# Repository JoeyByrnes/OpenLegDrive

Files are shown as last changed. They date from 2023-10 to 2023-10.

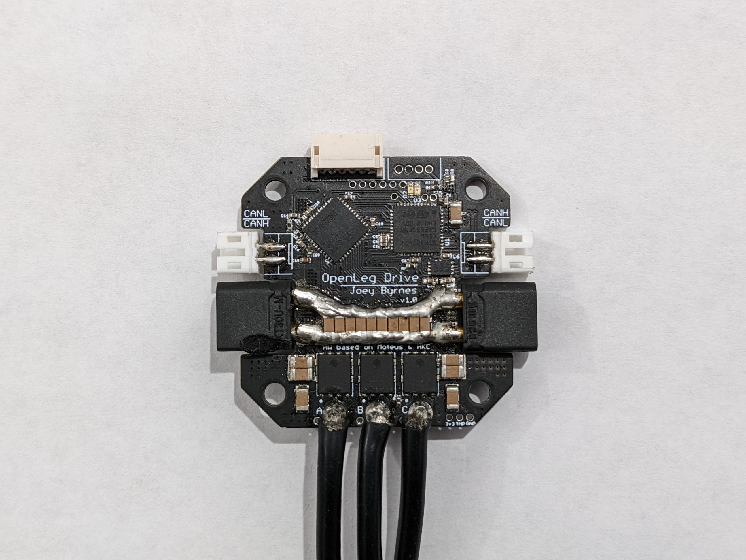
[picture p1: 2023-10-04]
readme-visuals/openlegdrive-top.jpg

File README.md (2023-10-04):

# OpenLeg Drive
Motor Controller for OpenLeg Actuators

This hardware is based on the <a href="https://github.com/mjbots">Moteus r4.5</a> by Josh Pieper at mjbots, and the firmware is ported from Ben Kat's <a href="https://github.com/bgkatz/motorcontrol">motorcontrol</a> project. See the <a href="https://github.com/JoeyByrnes/motorcontrolG4">motorcontrolG4</a> repo for the firmware.

<p align="center">
  
</p>

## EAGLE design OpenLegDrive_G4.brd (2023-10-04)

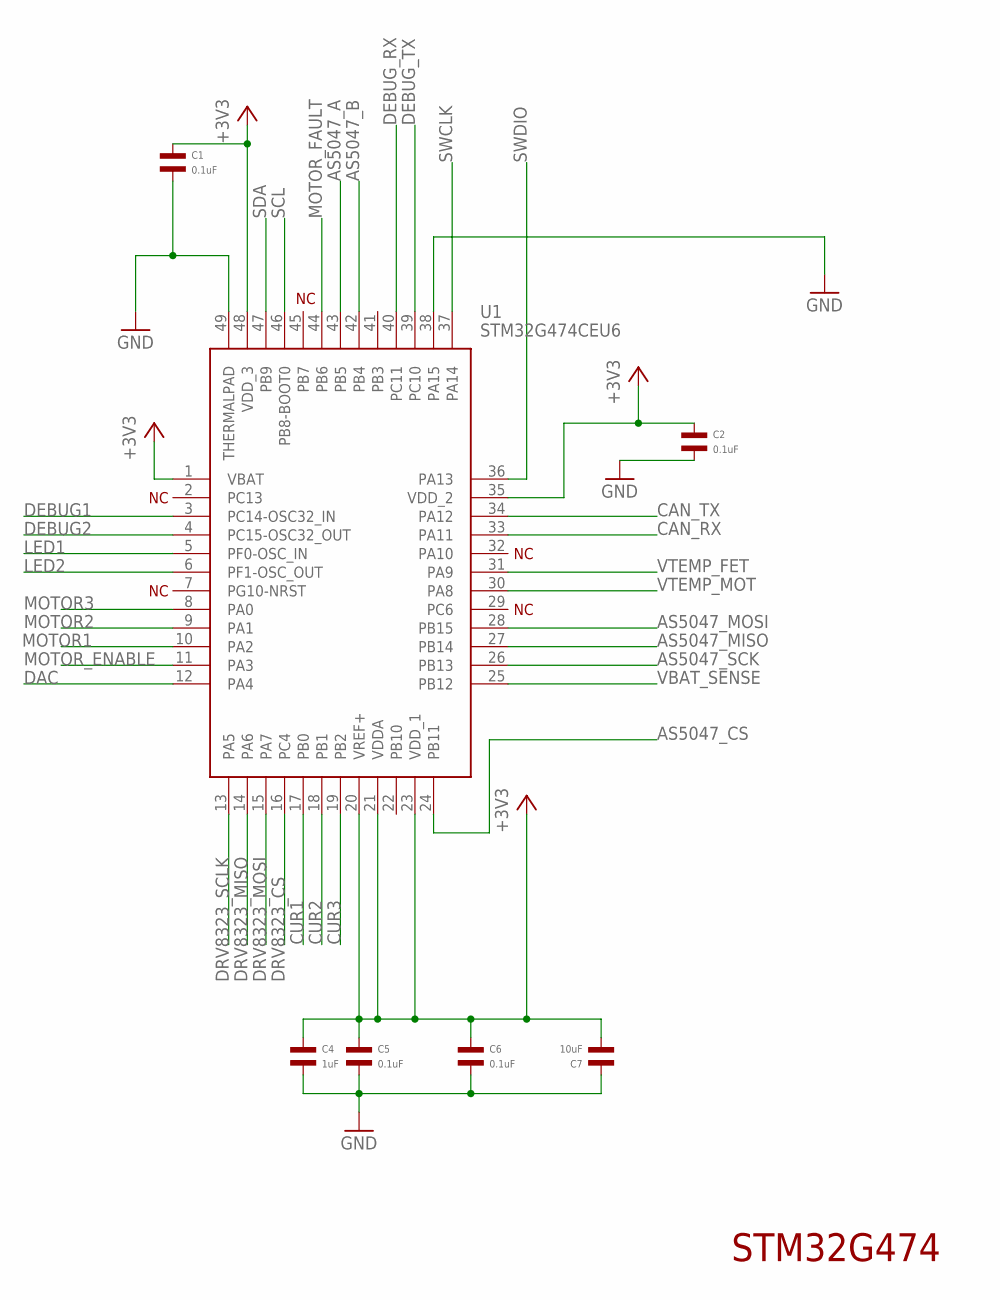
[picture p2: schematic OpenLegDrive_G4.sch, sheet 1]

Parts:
C1, C2, C5, C6: 0.1uF; C0402; MPN MF-CAP-0402-0.1uF
C4: 1uF; C0402; MPN MF-CAP-0402-1uF
C7: 10uF; C1206; MPN MF-CAP-1206-10uF
U1: STM32G474CEU6; QFN50P700X700X60-49N; MPN STM32G474CEU6

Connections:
3V3: C1.P$1, C2.P$1, C4.P$1, C5.P$1, C6.P$1, C7.P$2, U1.1 (VBAT), U1.20 (VREF+), U1.21 (VDDA), U1.23 (VDD_1), U1.35 (VDD_2), U1.48 (VDD_3); also elsewhere on the board
AS5047_A: U1.43 (PB5); also elsewhere on the board
AS5047_B: U1.42 (PB4); also elsewhere on the board
AS5047_CS: U1.24 (PB11); also elsewhere on the board
AS5047_MISO: U1.27 (PB14); also elsewhere on the board
AS5047_MOSI: U1.28 (PB15); also elsewhere on the board
AS5047_SCK: U1.26 (PB13); also elsewhere on the board
CAN_RX: U1.33 (PA11); also elsewhere on the board
CAN_TX: U1.34 (PA12); also elsewhere on the board
CUR1: U1.17 (PB0); also elsewhere on the board
CUR2: U1.18 (PB1); also elsewhere on the board
CUR3: U1.19 (PB2); also elsewhere on the board
DAC: U1.12 (PA4)
DEBUG1: U1.3 (PC14-OSC32_IN); also elsewhere on the board
DEBUG2: U1.4 (PC15-OSC32_OUT); also elsewhere on the board
DEBUG_RX: U1.40 (PC11); also elsewhere on the board
DEBUG_TX: U1.39 (PC10); also elsewhere on the board
DRV8323_CS: U1.16 (PC4); also elsewhere on the board
DRV8323_MISO: U1.14 (PA6); also elsewhere on the board
DRV8323_MOSI: U1.15 (PA7); also elsewhere on the board
DRV8323_SCLK: U1.13 (PA5); also elsewhere on the board
GND: C1.P$2, C2.P$2, C4.P$2, C5.P$2, C6.P$2, C7.P$1, U1.38 (PA15), U1.49 (THERMALPAD); also elsewhere on the board
LED1: U1.5 (PF0-OSC_IN); also elsewhere on the board
LED2: U1.6 (PF1-OSC_OUT); also elsewhere on the board
MOTOR1: U1.10 (PA2); also elsewhere on the board
MOTOR2: U1.9 (PA1); also elsewhere on the board
MOTOR3: U1.8 (PA0); also elsewhere on the board
MOTOR_ENABLE: U1.11 (PA3); also elsewhere on the board
MOTOR_FAULT: U1.44 (PB6); also elsewhere on the board
SCL: U1.46 (PB8-BOOT0); also elsewhere on the board
SDA: U1.47 (PB9); also elsewhere on the board
SWCLK: U1.37 (PA14); also elsewhere on the board
SWDIO: U1.36 (PA13); also elsewhere on the board
VBAT_SENSE: U1.25 (PB12); also elsewhere on the board
VTEMP_FET: U1.31 (PA9); also elsewhere on the board
VTEMP_MOT: U1.30 (PA8); also elsewhere on the board

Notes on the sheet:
STM32G474

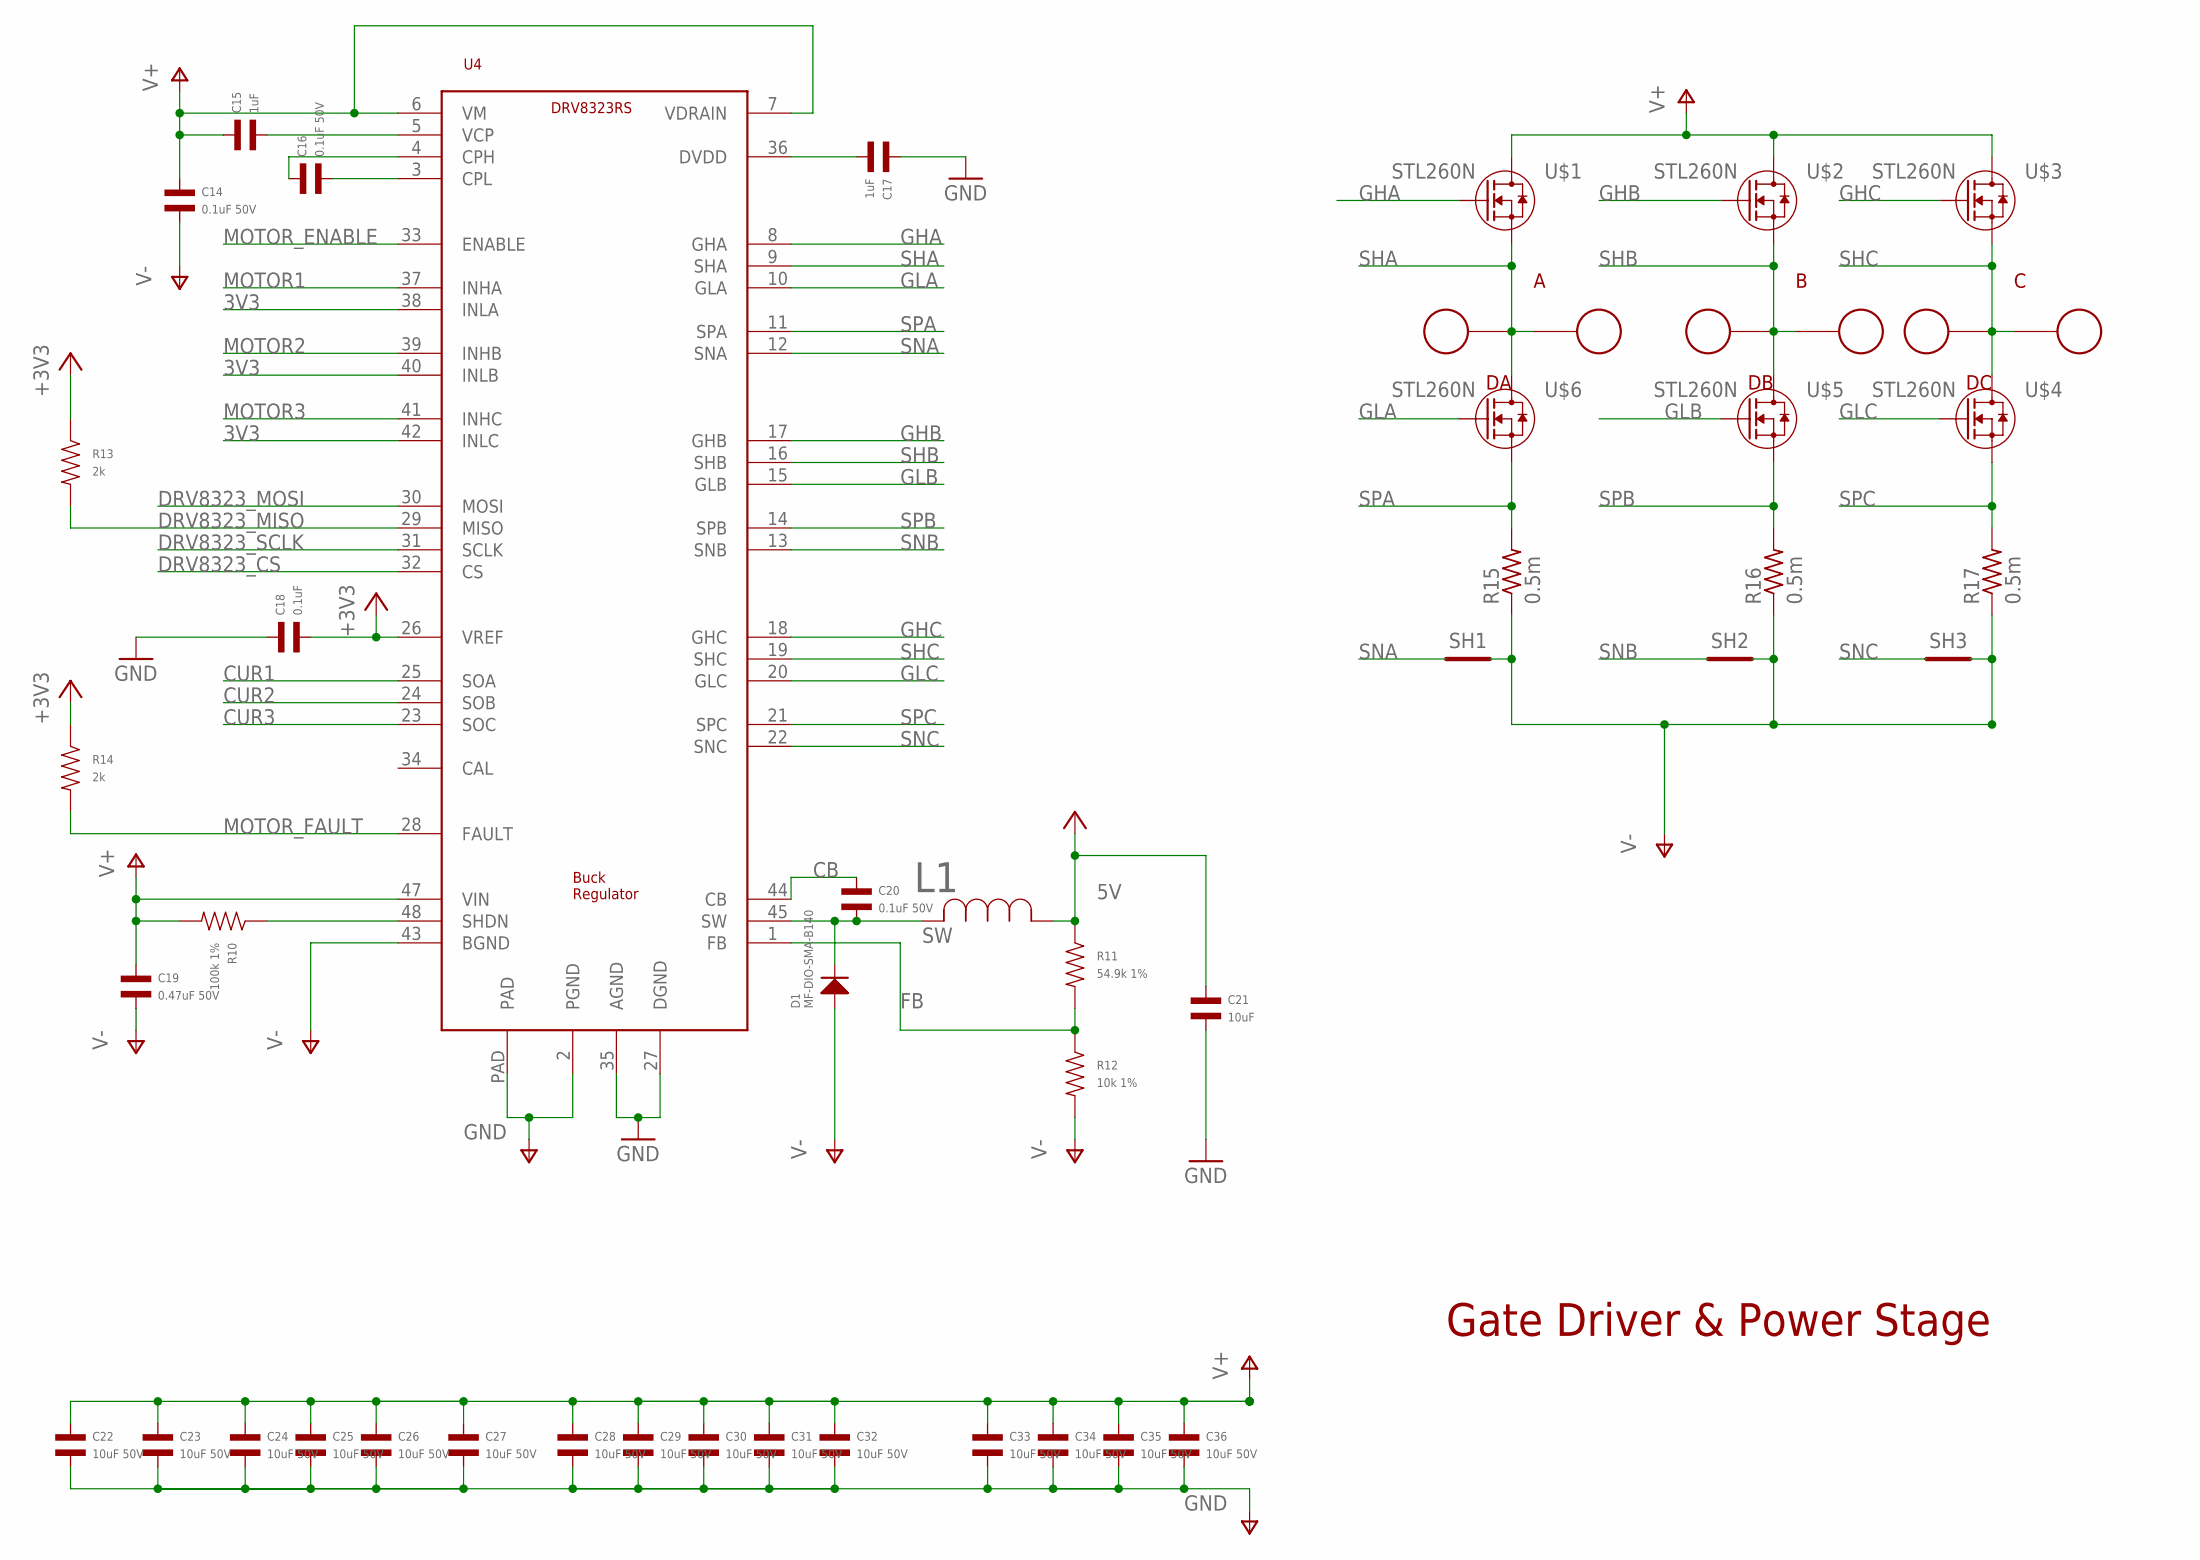
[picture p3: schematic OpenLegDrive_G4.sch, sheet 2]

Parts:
A: PAD16AWG_PAD; 16AWG_PAD
B: PAD16AWG_PAD; 16AWG_PAD
C: PAD16AWG_PAD; 16AWG_PAD
C14, C16, C20: 0.1uF 50V; C0402; MPN CGA2B3X7R1H104K050BB
C15, C17: 1uF; C0402; MPN MF-CAP-0402-1uF
C18: 0.1uF; C0402; MPN MF-CAP-0402-0.1uF
C19: 0.47uF 50V; C0402; MPN UMK105ABJ474KV-F
C21: 10uF; C1206; MPN MF-CAP-1206-10uF
C22, C23, C24, C25, C26, C27, C28, C29, C30, C31, C32, C33, C34, C35, C36: 10uF 50V; C1206; MPN C3216X7R1H106K160AE
D1: MF-DIO-SMA-B140; SMA
DA: PAD24AWG_PAD; 24AWG_PAD
DB: PAD24AWG_PAD; 24AWG_PAD
DC: PAD24AWG_PAD; 24AWG_PAD
L1: SRN4018-220M; IND_BOURNS_SRN4018; MPN SRN4018-220M
R10: 100k 1%; R0402; MPN ERJ-2RKF1003X
R11: 54.9k 1%; R0402; MPN ERJ-2RKF3302X
R12: 10k 1%; R0402; MPN ERJ-2RKF1002X
R13, R14: 2k; R0402; MPN MF-RES-0402-2K
R15, R16, R17: 0.5m; R1210
SH1, SH2, SH3: SHORTT5; SHORT_TOP-50
U4: DRV8323RS; PVQFN-N48; MPN DRV8323RSRGZR
U$1, U$2, U$3, U$4, U$5, U$6: STL260N; POWERFLAT_5X6

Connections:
3V3: C18.P$2, R13.P$1, R14.P$1, U4.26 (VREF), U4.38 (INLA), U4.40 (INLB), U4.42 (INLC); also elsewhere on the board
5V: C21.P$1, L1.1, R11.P$1; also elsewhere on the board
CB: C20.P$1, U4.44 (CB)
CUR1: U4.25 (SOA); also elsewhere on the board
CUR2: U4.24 (SOB); also elsewhere on the board
CUR3: U4.23 (SOC); also elsewhere on the board
DRV8323_CS: U4.32 (CS); also elsewhere on the board
DRV8323_MISO: R13.P$2, U4.29 (MISO); also elsewhere on the board
DRV8323_MOSI: U4.30 (MOSI); also elsewhere on the board
DRV8323_SCLK: U4.31 (SCLK); also elsewhere on the board
FB: R11.P$2, R12.P$1, U4.1 (FB)
GHA: U4.8 (GHA), U$1.4 (G)
GHB: U4.17 (GHB), U$2.4 (G)
GHC: U4.18 (GHC), U$3.4 (G)
GLA: U4.10 (GLA), U$6.4 (G)
GLB: U4.15 (GLB), U$5.4 (G)
GLC: U4.20 (GLC), U$4.4 (G)
GND: C14.P$2, C17.P$1, C18.P$1, C19.P$2, C21.P$2, C22.P$2, C23.P$2, C24.P$2, C25.P$2, C26.P$2, C27.P$2, C28.P$2, C29.P$2, C30.P$2, C31.P$2, C32.P$2, C33.P$2, C34.P$2, C35.P$2, C36.P$2, D1.ANODE, R12.P$2, R15.1, R16.1, R17.1, SH1.2, SH2.2, SH3.2, U4.2 (PGND), U4.27 (DGND), U4.35 (AGND), U4.43 (BGND), U4.PAD; also elsewhere on the board
MOTOR1: U4.37 (INHA); also elsewhere on the board
MOTOR2: U4.39 (INHB); also elsewhere on the board
MOTOR3: U4.41 (INHC); also elsewhere on the board
MOTOR_ENABLE: U4.33 (ENABLE); also elsewhere on the board
MOTOR_FAULT: R14.P$2, U4.28 (FAULT); also elsewhere on the board
unnamed: R10.P$1, U4.48 (SHDN)
unnamed: C16.P$2, U4.3 (CPL)
unnamed: C16.P$1, U4.4 (CPH)
unnamed: C15.P$2, U4.5 (VCP)
unnamed: C17.P$2, U4.36 (DVDD)
SHA: A.1, DA.P$1, U4.9 (SHA), U$1.1 (S), U$1.2 (S), U$1.3 (S), U$6.5 (D), U$6.6 (D), U$6.7 (D), U$6.8 (D)
SHB: B.1, DB.P$1, U4.16 (SHB), U$2.1 (S), U$2.2 (S), U$2.3 (S), U$5.5 (D), U$5.6 (D), U$5.7 (D), U$5.8 (D)
SHC: C.1, DC.P$1, U4.19 (SHC), U$3.1 (S), U$3.2 (S), U$3.3 (S), U$4.5 (D), U$4.6 (D), U$4.7 (D), U$4.8 (D)
SNA: SH1.1, U4.12 (SNA)
SNB: SH2.1, U4.13 (SNB)
SNC: SH3.1, U4.22 (SNC)
SPA: R15.2, U4.11 (SPA), U$6.1 (S), U$6.2 (S), U$6.3 (S)
SPB: R16.2, U4.14 (SPB), U$5.1 (S), U$5.2 (S), U$5.3 (S)
SPC: R17.2, U4.21 (SPC), U$4.1 (S), U$4.2 (S), U$4.3 (S)
SW: C20.P$2, D1.CATHODE, L1.2, U4.45 (SW)
V+: C14.P$1, C15.P$1, C19.P$1, C22.P$1, C23.P$1, C24.P$1, C25.P$1, C26.P$1, C27.P$1, C28.P$1, C29.P$1, C30.P$1, C31.P$1, C32.P$1, C33.P$1, C34.P$1, C35.P$1, C36.P$1, R10.P$2, U4.6 (VM), U4.7 (VDRAIN), U4.47 (VIN), U$1.5 (D), U$1.6 (D), U$1.7 (D), U$1.8 (D), U$2.5 (D), U$2.6 (D), U$2.7 (D), U$2.8 (D), U$3.5 (D), U$3.6 (D), U$3.7 (D), U$3.8 (D); also elsewhere on the board

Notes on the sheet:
Gate Driver & Power Stage

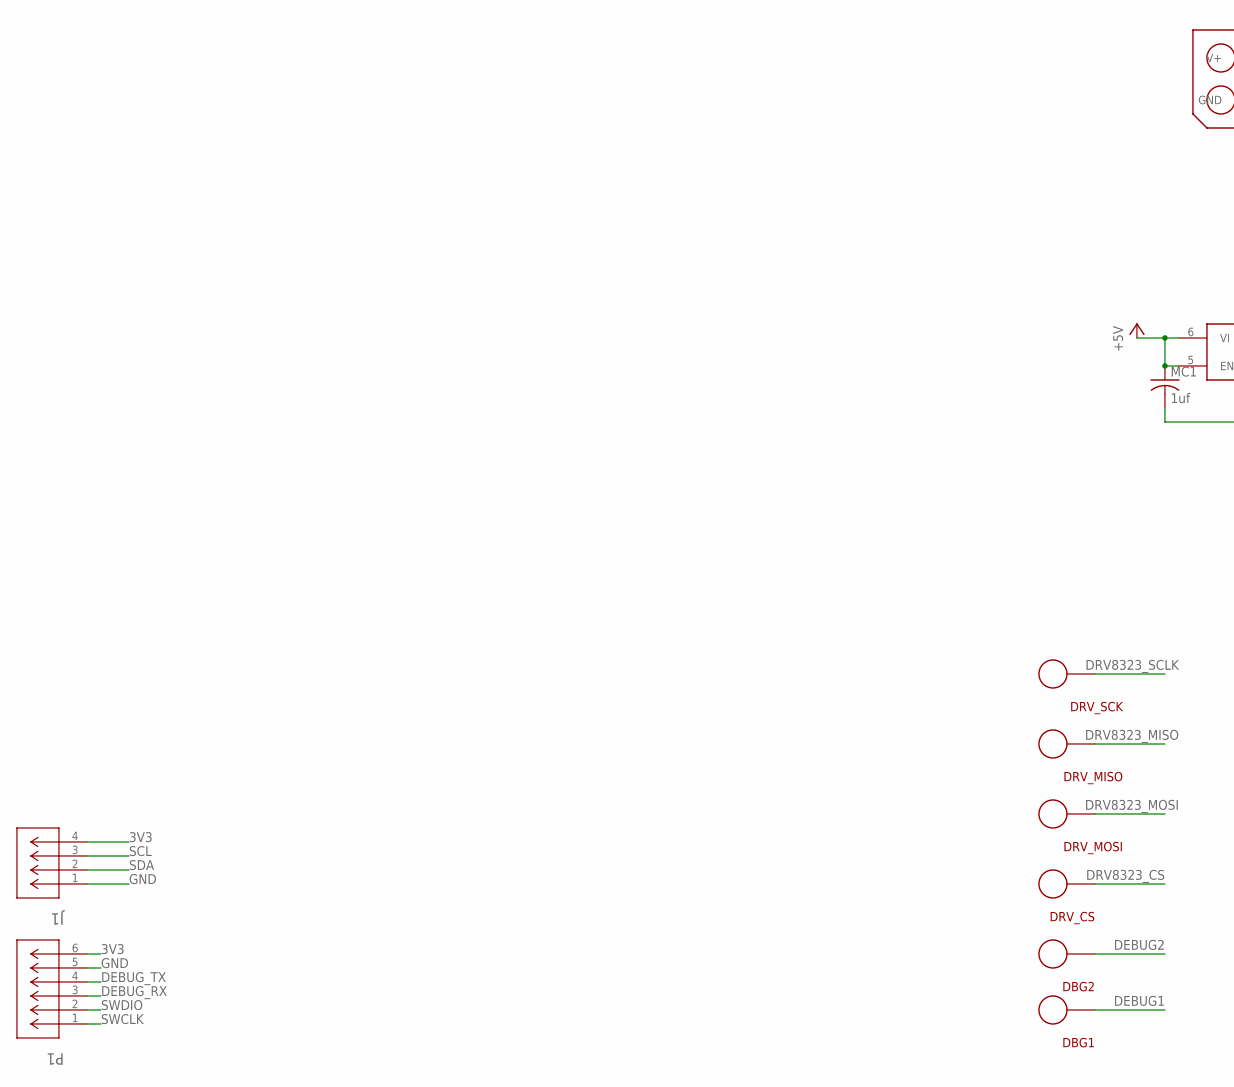
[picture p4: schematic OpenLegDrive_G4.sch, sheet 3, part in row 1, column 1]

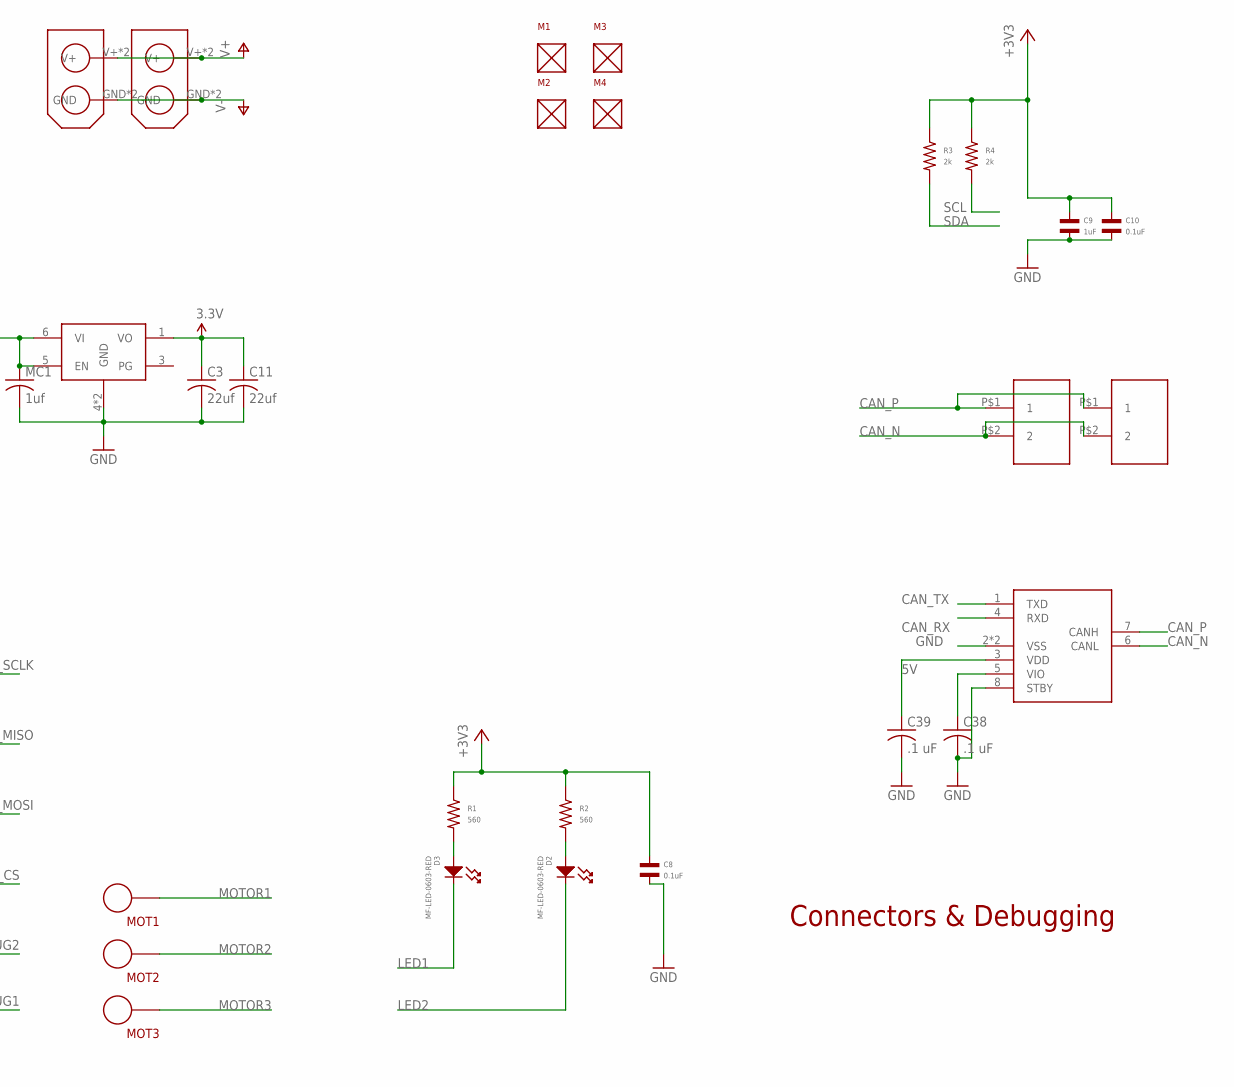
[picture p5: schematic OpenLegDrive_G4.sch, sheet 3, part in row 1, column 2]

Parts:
C3, C11: 22uf; C0603K
C8, C10: 0.1uF; C0402; MPN MF-CAP-0402-0.1uF
C9: 1uF; C0402; MPN MF-CAP-0402-1uF
C38, C39: .1 uF; C0402K
D2: MF-LED-0603-RED; LED0603; MPN MF-LED-0603-GREEN
D3: MF-LED-0603-RED; LED0603
DBG1, DBG2: PAD24AWG_PAD; 24AWG_PAD
DRV_CS: PAD24AWG_PAD; 24AWG_PAD
DRV_MISO: PAD24AWG_PAD; 24AWG_PAD
DRV_MOSI: PAD24AWG_PAD; 24AWG_PAD
DRV_SCK: PAD24AWG_PAD; 24AWG_PAD
J1: S4B-ZR(LF)(SN); CONN_S4B-ZR(LF)(SN)_JST
M1, M2, M3, M4: MOUNT; M2.5MOUNT
MC1: 1uf; C0402
MOT1, MOT2, MOT3: PAD24AWG_PAD; 24AWG_PAD
P1: S6B-ZR(LF)(SN); S6B-ZR_JST
R1, R2: 560; R0402; MPN MF-RES-0402-560
R3, R4: 2k; R0402; MPN MF-RES-0402-2K
U$7: XT30_DUAL_MOUNT_FLIPPED; XT30_DUAL_FLIPPED
U$8: XT30_DUAL_MOUNT; XT30_DUAL
U$9, U$10: JST-PH-DOUBLE-2-PIN; JST-PH_DUALMOUNT-2
U$11: LDFM; DFN6-3X3
U$12: MCP2542; TDFN

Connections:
3V3: C3.1, C8.P$1, C9.P$1, C10.P$1, C11.1, C38.1, J1.4, P1.6, R1.P$1, R2.P$1, R3.P$1, R4.P$1, U$11.1 (VO), U$12.5 (VIO); also elsewhere on the board
5V: C39.1, MC1.1, U$11.5 (EN), U$11.6 (VI), U$12.3 (VDD); also elsewhere on the board
CAN_N: U$9.P$2 (2), U$10.P$2 (2), U$12.6 (CANL)
CAN_P: U$9.P$1 (1), U$10.P$1 (1), U$12.7 (CANH)
CAN_RX: U$12.4 (RXD); also elsewhere on the board
CAN_TX: U$12.1 (TXD); also elsewhere on the board
DEBUG1: DBG1.P$1; also elsewhere on the board
DEBUG2: DBG2.P$1; also elsewhere on the board
DEBUG_RX: P1.3; also elsewhere on the board
DEBUG_TX: P1.4; also elsewhere on the board
DRV8323_CS: DRV_CS.P$1; also elsewhere on the board
DRV8323_MISO: DRV_MISO.P$1; also elsewhere on the board
DRV8323_MOSI: DRV_MOSI.P$1; also elsewhere on the board
DRV8323_SCLK: DRV_SCK.P$1; also elsewhere on the board
GND: C3.2, C8.P$2, C9.P$2, C10.P$2, C11.2, C38.2, C39.2, J1.1, MC1.2, P1.5, U$7.GND, U$7.GND@1 (GND), U$8.GND, U$8.GND@1 (GND), U$11.4 (GND), U$11.EXP (GND), U$12.2 (VSS), U$12.8 (STBY), U$12.9 (VSS); also elsewhere on the board
LED1: D3.CATHODE; also elsewhere on the board
LED2: D2.CATHODE; also elsewhere on the board
MOTOR1: MOT1.P$1; also elsewhere on the board
MOTOR2: MOT2.P$1; also elsewhere on the board
MOTOR3: MOT3.P$1; also elsewhere on the board
unnamed: D3.ANODE, R1.P$2
unnamed: D2.ANODE, R2.P$2
SCL: J1.3, R4.P$2; also elsewhere on the board
SDA: J1.2, R3.P$2; also elsewhere on the board
SWCLK: P1.1; also elsewhere on the board
SWDIO: P1.2; also elsewhere on the board
V+: U$7.V+, U$7.V+@1 (V+), U$8.V+, U$8.V+@1 (V+); also elsewhere on the board

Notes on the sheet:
Connectors & Debugging

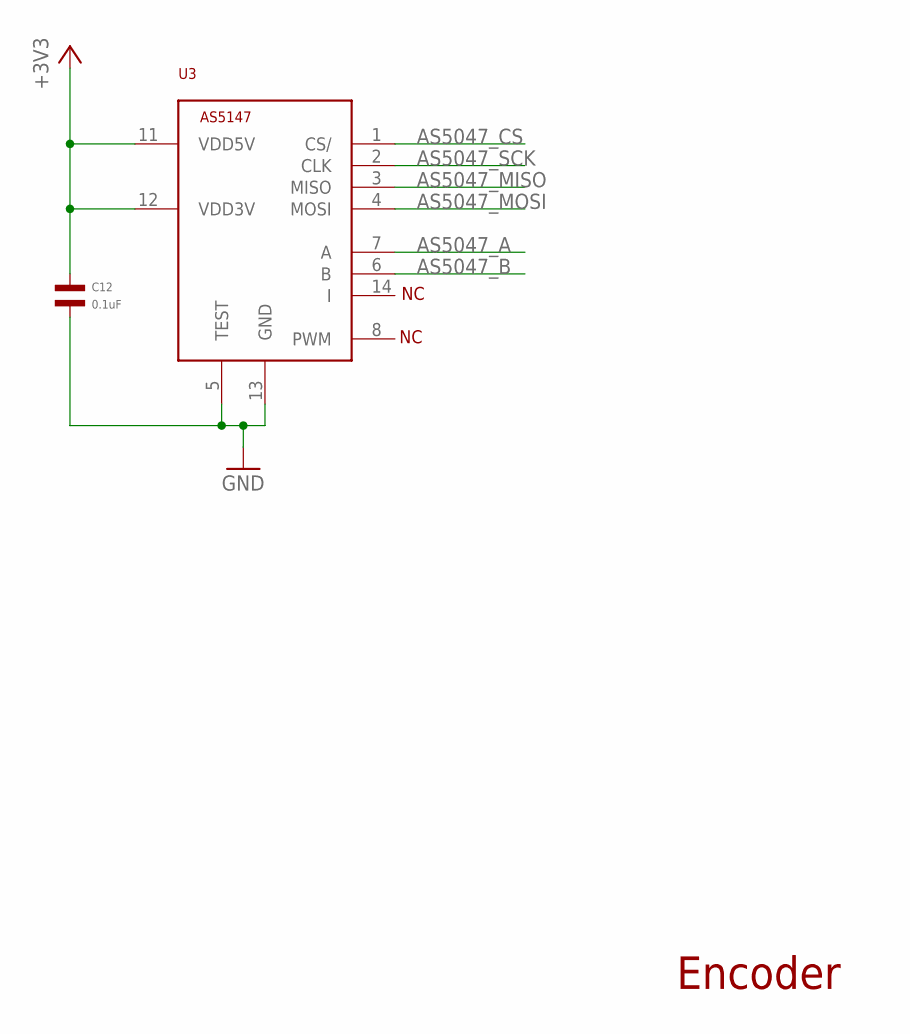
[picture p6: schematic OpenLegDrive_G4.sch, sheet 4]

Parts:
C12: 0.1uF; C0402; MPN MF-CAP-0402-0.1uF
U3: AS5147; TSSOP14; MPN AS5047P-ATSM

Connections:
3V3: C12.P$1, U3.11 (VDD5V), U3.12 (VDD3V); also elsewhere on the board
AS5047_A: U3.7 (A); also elsewhere on the board
AS5047_B: U3.6 (B); also elsewhere on the board
AS5047_CS: U3.1 (CS/); also elsewhere on the board
AS5047_MISO: U3.3 (MISO); also elsewhere on the board
AS5047_MOSI: U3.4 (MOSI); also elsewhere on the board
AS5047_SCK: U3.2 (CLK); also elsewhere on the board
GND: C12.P$2, U3.5 (TEST), U3.13 (GND); also elsewhere on the board

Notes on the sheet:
Encoder

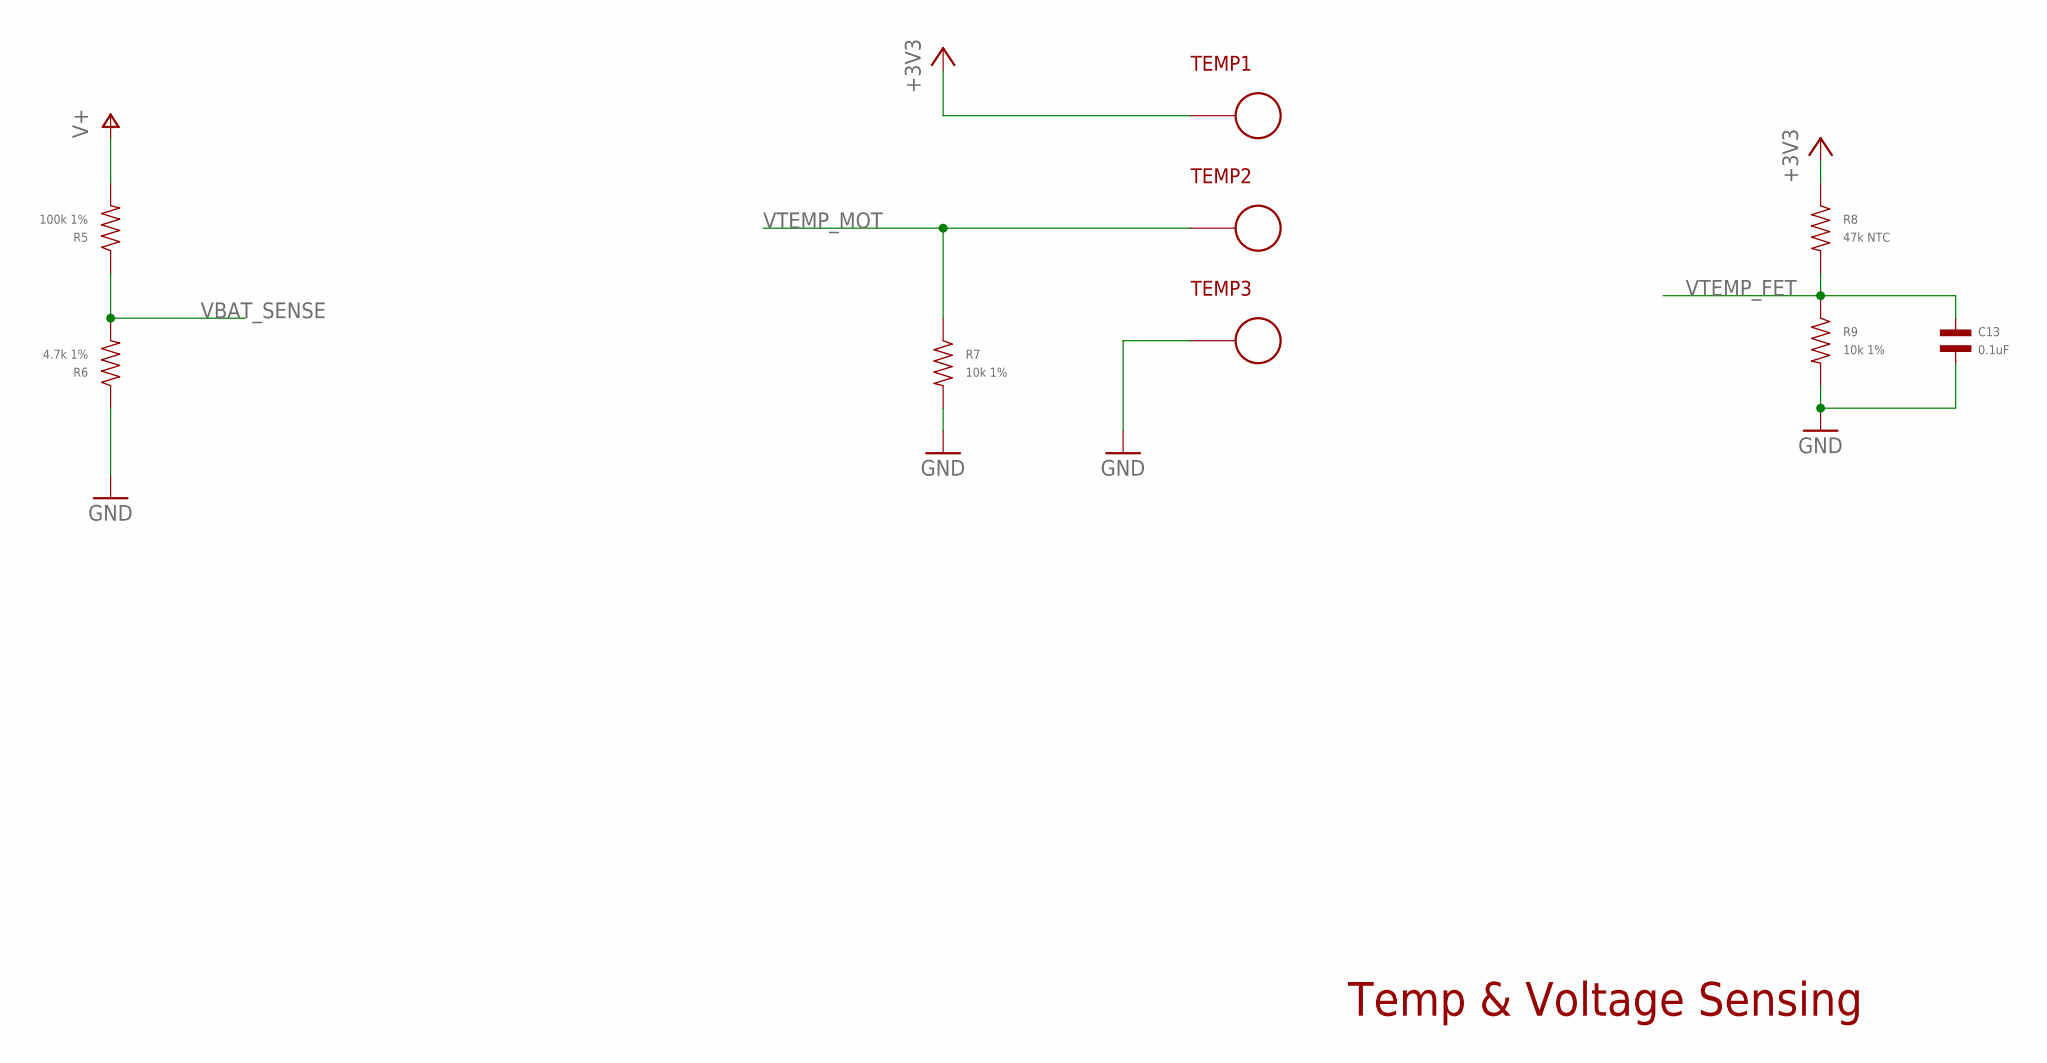
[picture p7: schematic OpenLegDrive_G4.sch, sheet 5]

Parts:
C13: 0.1uF; C0402; MPN MF-CAP-0402-0.1uF
R5: 100k 1%; R0402; MPN ERJ-2RKF1003X
R6: 4.7k 1%; R0402; MPN ERJ-2RKF4701X
R7, R9: 10k 1%; R0402; MPN ERJ-2RKF1002X
R8: 47k NTC; R0402; MPN NCP15WB473F03RC
TEMP1, TEMP2, TEMP3: PAD24AWG_PAD; 24AWG_PAD

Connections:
3V3: R8.P$1, TEMP1.P$1; also elsewhere on the board
GND: C13.P$2, R6.P$1, R7.P$2, R9.P$2, TEMP3.P$1; also elsewhere on the board
V+: R5.P$2; also elsewhere on the board
VBAT_SENSE: R5.P$1, R6.P$2; also elsewhere on the board
VTEMP_FET: C13.P$1, R8.P$2, R9.P$1; also elsewhere on the board
VTEMP_MOT: R7.P$1, TEMP2.P$1; also elsewhere on the board

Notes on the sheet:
Temp & Voltage Sensing

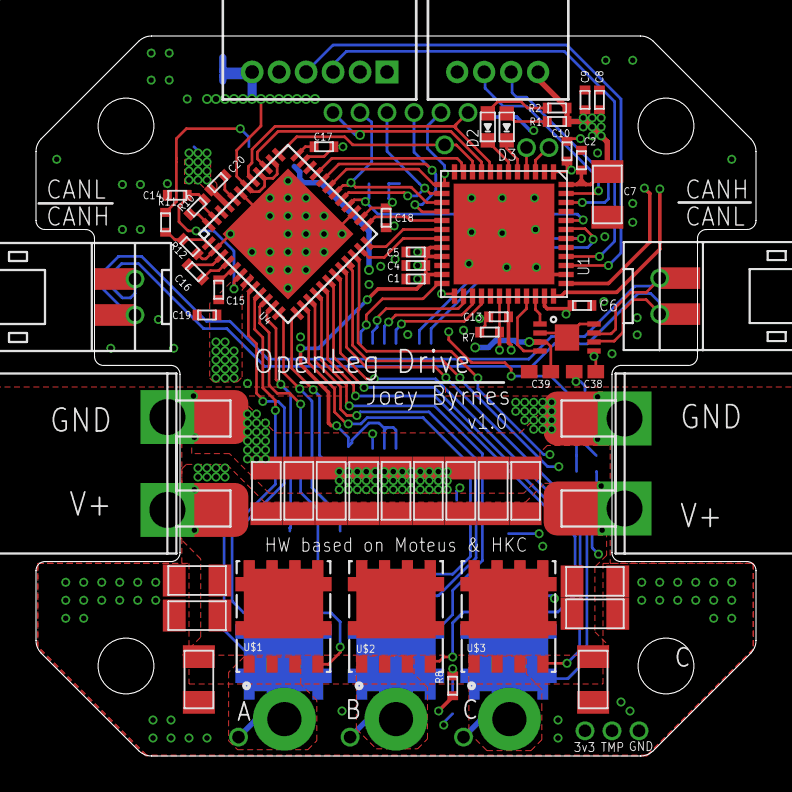
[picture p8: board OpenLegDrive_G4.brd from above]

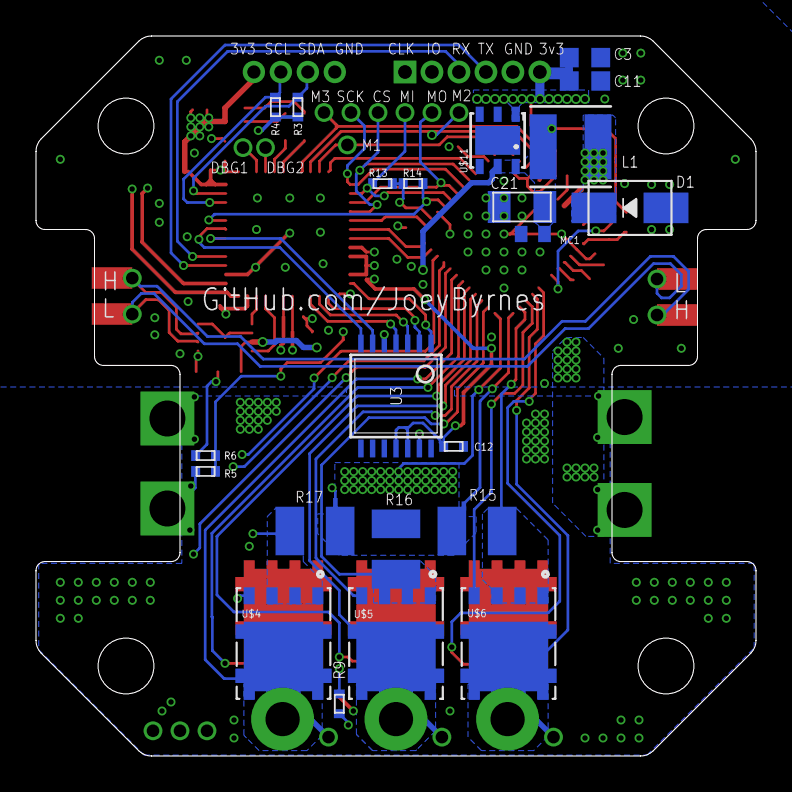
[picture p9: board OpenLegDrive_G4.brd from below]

Board: 4 copper layers, 40.0 x 40.0 mm, 102 parts (25 on the bottom side), 64 nets.

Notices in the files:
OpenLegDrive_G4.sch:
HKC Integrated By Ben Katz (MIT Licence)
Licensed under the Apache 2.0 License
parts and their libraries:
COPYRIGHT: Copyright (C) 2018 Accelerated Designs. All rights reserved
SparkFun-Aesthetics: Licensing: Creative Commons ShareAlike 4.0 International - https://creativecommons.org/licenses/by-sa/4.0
